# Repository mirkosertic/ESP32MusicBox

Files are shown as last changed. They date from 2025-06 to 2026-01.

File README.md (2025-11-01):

# ESP32 MusicBox



This project provides an ESP32 based music box with the following features:

* Simple 3-button control
* MP3 playback
* Integration with I2C RFID tag scanner
* Support for WiFi Grids with auto-reconnect to nearest access point
* MQTT status reporting / remote control
* Home Assistant integration with device autodiscovery
* Web-based user interface
* Integrated into your local network with SSDP / mDNS protocol
* WebDAV support for file / content management
* Optional Bluetooth A2DP output / Bluetooth Headphone output
* Special mode to start in Bluetooth Speaker mode, so it works as a Boombox.
* 3-band equalizer

## Supported hardware

* ESP32 (tested with Lolin D32 Pro with a lot of PSRAM recommended (8 MB), 4MB flash RAM is required)
* PN532 RFID Reader (i2c-Mode)
* SDCard Reader (SPI-Mode), is already mounted on a Lolin D32 Pro board
* NeoPixel / WS2812 based LEDs for status visualization

## Final product

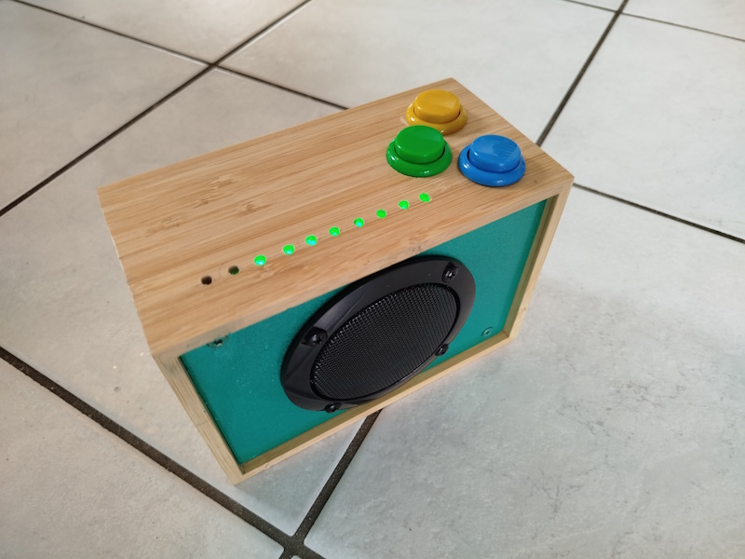
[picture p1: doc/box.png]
box


The KiCad 9.0 project is located in the kicad folder.

Here is the wiring schematic drawing:

schematics

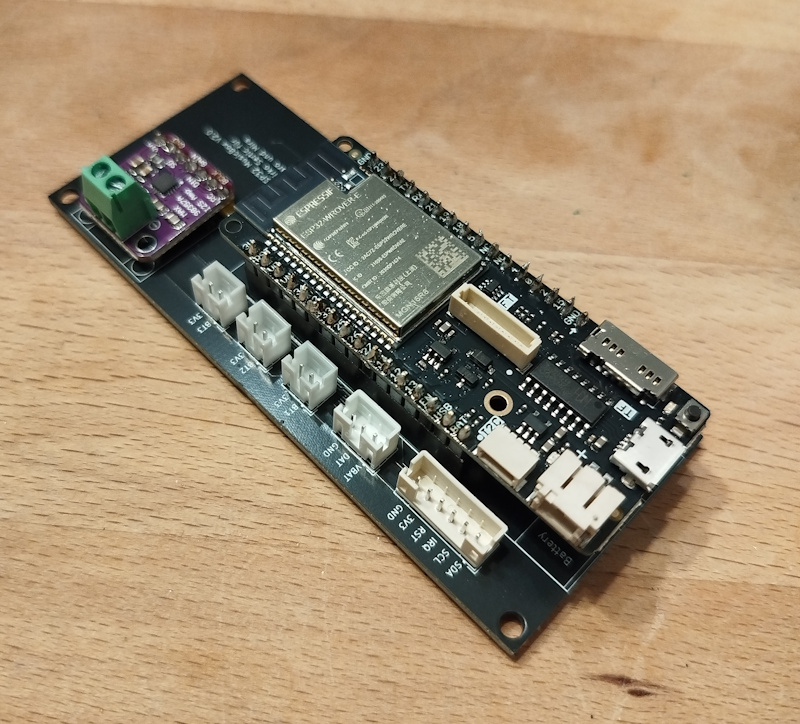
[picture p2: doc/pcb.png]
pcb


## Manual

Status visualization with LEDs:

- Boot-Sequence - LEDs enabled step by step to visualize boot progress
- Leds cycling in brightness - orange in case WiFi is not connected but enabled, green in case if playback paused or no playback yet
- Leds green from 0% to 100% filling the circle - Playback progress while playing something
- Leds blinking red - Unknown RFID card detected
- Leds blinking green - RFID card programmed / Known card detected
- Leds green to red - While changing volume
- Keep button 1 pressed during startup. Leds will turn blue to indicate Bluetooth Speaker mode.
- Yellow flashing LEDs indicate a Bluetooth pairing request while in Speaker mode. Press button 1 again to confirm the pairing. LEDs will flash in blue to confirm pairing
- Keep button 1 and button 2 pressed during playback to start from beginning

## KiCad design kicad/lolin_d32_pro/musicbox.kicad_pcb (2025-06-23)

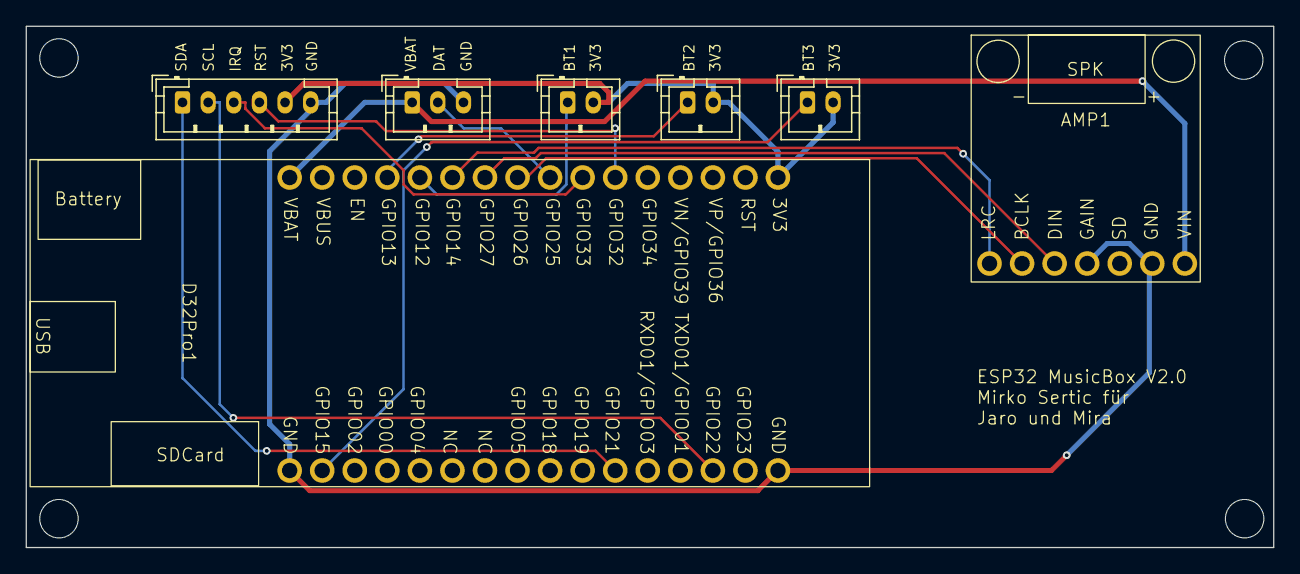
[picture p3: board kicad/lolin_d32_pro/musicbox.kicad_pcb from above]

Board: 2 copper layers, 97.3 x 40.7 mm, 7 parts (0 on the bottom side), 14 nets.

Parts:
AMP1: MAX98357A
BT1Con1, BT2Con1, BT3Con1: JST_PH_B2B-PH-K_1x02_P2.00mm_Vertical
D32Pro1: ESPD32Pro
NeoPixelCon1: JST_PH_B3B-PH-K_1x03_P2.00mm_Vertical
RFIDCon1: Conn_01x06_Socket; JST_PH_B6B-PH-K_1x06_P2.00mm_Vertical

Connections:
3V3: BT1Con1.2, BT2Con1.2, BT3Con1.2, D32Pro1.1 (3V3), RFIDCon1.5
/ADR_LED: D32Pro1.8 (GPIO25), NeoPixelCon1.2
/BT1: BT1Con1.1, D32Pro1.12 (GPIO12)
/BT2: BT2Con1.1, D32Pro1.13 (GPIO13)
/BT3: BT3Con1.1, D32Pro1.31 (GPIO15)
/I2C_SCL: D32Pro1.19 (GPIO22), RFIDCon1.2
/I2C_SDA: D32Pro1.22 (GPIO21), RFIDCon1.1
/I2S_BCK: AMP1.2 (BCLK), D32Pro1.9 (GPIO26)
/I2S_DIN: AMP1.3 (DIN), D32Pro1.10 (GPIO27)
/I2S_WS: AMP1.1 (LRC), D32Pro1.11 (GPIO14)
/RFID_IRQ: D32Pro1.7 (GPIO33), RFIDCon1.3
/RFID_RST: D32Pro1.6 (GPIO32), RFIDCon1.4
GND: AMP1.4 (GAIN), AMP1.6 (GND), D32Pro1.17 (GND), D32Pro1.32 (GND), NeoPixelCon1.3, RFIDCon1.6
VBAT: AMP1.7 (VIN), D32Pro1.16 (VBAT), NeoPixelCon1.1

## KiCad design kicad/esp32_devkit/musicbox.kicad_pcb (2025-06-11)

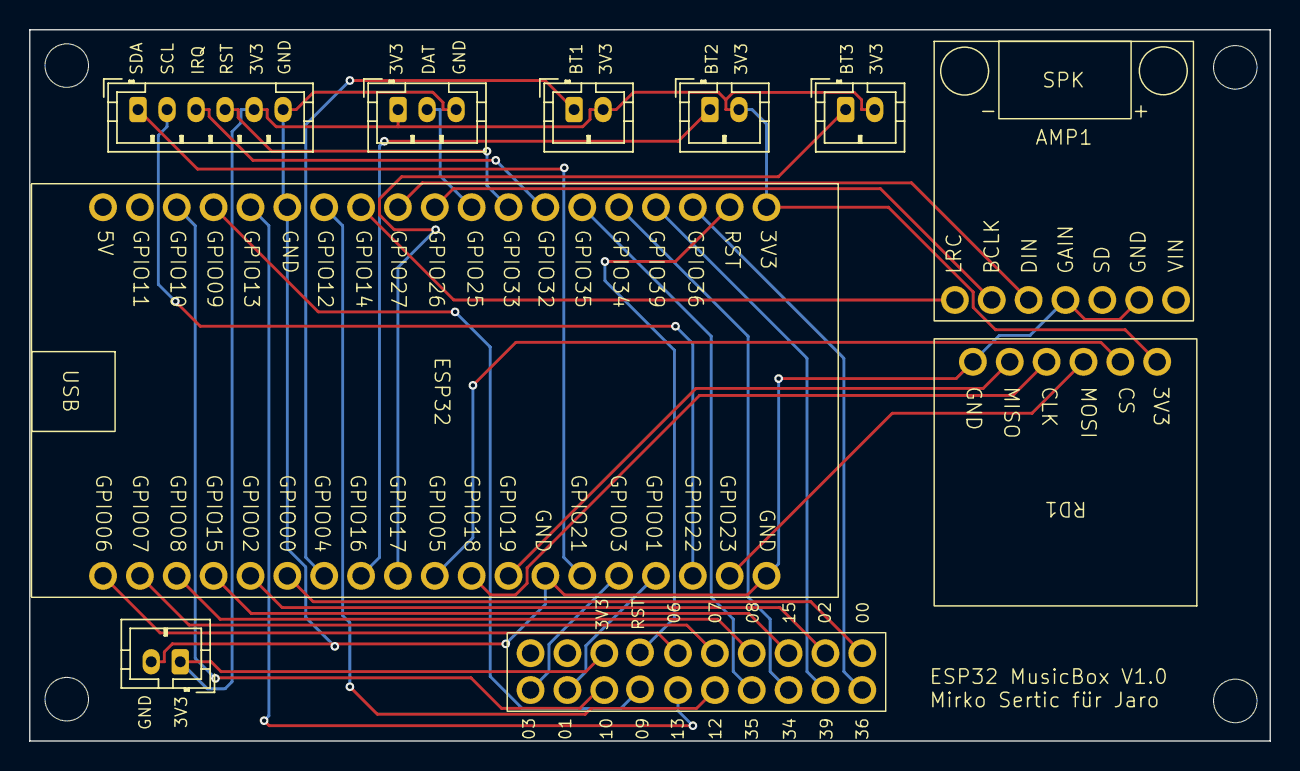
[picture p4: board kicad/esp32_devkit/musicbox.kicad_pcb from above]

Board: 2 copper layers, 85.5 x 49.0 mm, 10 parts (0 on the bottom side), 34 nets.

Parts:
AMP1: MAX98357A
BT1Con1, BT2Con1, BT3Con1: JST_PH_B2B-PH-K_1x02_P2.00mm_Vertical
ESP32: ESP32DevKit
IO1: IO; Pads_2x10
NeoPixelCon1: JST_PH_B3B-PH-K_1x03_P2.00mm_Vertical
PWRCon1: JST_PH_B2B-PH-K_1x02_P2.00mm_Vertical
RD1: SDCardReader
RFIDCon1: Conn_01x06_Socket; JST_PH_B6B-PH-K_1x06_P2.00mm_Vertical

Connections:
3V3: BT1Con1.2, BT2Con1.2, BT3Con1.2, ESP32.1 (3V3), IO1.18, NeoPixelCon1.1, PWRCon1.1, RD1.1 (VCC), RFIDCon1.5
/ADR_LED: ESP32.9 (GPIO25), NeoPixelCon1.2
/BT1: BT1Con1.1, ESP32.32 (GPIO04)
/BT2: BT2Con1.1, ESP32.31 (GPIO16)
/BT3: BT3Con1.1, ESP32.30 (GPIO17)
/GPIO00: ESP32.33 (GPIO00), IO1.11
/GPIO01: ESP32.23 (GPIO01), IO1.9
/GPIO02: ESP32.34 (GPIO02), IO1.12
/GPIO03: ESP32.24 (GPIO03), IO1.10
/GPIO06: ESP32.38 (GPIO06), IO1.16
/GPIO07: ESP32.37 (GPIO07), IO1.15
/GPIO08: ESP32.36 (GPIO08), IO1.14
/GPIO09: ESP32.16 (GPIO09), IO1.7
/GPIO10: ESP32.17 (GPIO10), IO1.8
/GPIO12: ESP32.13 (GPIO12), IO1.5
/GPIO13: ESP32.15 (GPIO13), IO1.6
/GPIO15: ESP32.35 (GPIO15), IO1.13
/GPIO34: ESP32.5 (GPIO34), IO1.3
/GPIO35: ESP32.6 (GPIO35), IO1.4
/GPIO36: ESP32.3 (GPIO36), IO1.1
/GPIO39: ESP32.4 (GPIO39), IO1.2
/I2C_SCL: ESP32.22 (GPIO22), RFIDCon1.2
/I2C_SDA: ESP32.25 (GPIO21), RFIDCon1.1
/I2S_BCK: AMP1.2 (BCLK), ESP32.10 (GPIO26)
/I2S_DIN: AMP1.3 (DIN), ESP32.11 (GPIO27)
/I2S_WS: AMP1.1 (LRC), ESP32.12 (GPIO14)
/RFID_IRQ: ESP32.7 (GPIO32), RFIDCon1.3
/RFID_RST: ESP32.8 (GPIO33), RFIDCon1.4
/RST: ESP32.2 (RESET), IO1.17
/SPI_MISO: ESP32.27 (GPIO19), RD1.5 (MISO)
/SPI_MOSI: ESP32.21 (GPIO23), RD1.3 (MOSI)
/SPI_SCK: ESP32.28 (GPIO18), RD1.4 (SCK)
/SPI_SS: ESP32.29 (GPIO05), RD1.2 (CS)
GND: AMP1.4 (GAIN), AMP1.6 (GND), ESP32.14 (GND), ESP32.20 (GND), ESP32.26 (GND), NeoPixelCon1.3, PWRCon1.2, RD1.6 (GND), RFIDCon1.6

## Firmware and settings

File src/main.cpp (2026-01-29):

#include "boomboxmode.h"
#include "leds.h"
#include "logging.h"
#include "pins.h"
#include "rfidplayermode.h"
#include "sensors.h"

#include <driver/rtc_io.h>
#include <esp_arduino_version.h>
#include <esp_idf_version.h>
#include <esp_sleep.h>
#include <esp_task_wdt.h>

Leds *leds = NULL;
Sensors *sensors = NULL;
Mode *mode = NULL;

void setup() {
	Serial.begin(115200);

	INFO("Setup started");
	INFO("Running on Arduino : %d.%d.%d", ESP_ARDUINO_VERSION_MAJOR, ESP_ARDUINO_VERSION_MINOR, ESP_ARDUINO_VERSION_PATCH);
	INFO("Running on ESP IDF : %s", esp_get_idf_version());
	INFO("Max  HEAP  is %d", ESP.getHeapSize());
	INFO("Free HEAP  is %d", ESP.getFreeHeap());
	INFO("Max  PSRAM is %d", ESP.getPsramSize());
	INFO("Free PSRAM is %d", ESP.getFreePsram());

	esp_sleep_wakeup_cause_t wakeupreason = esp_sleep_get_wakeup_cause();
	switch (wakeupreason) {
		case ESP_SLEEP_WAKEUP_EXT0: {
			INFO("Deepsleep Wakeup EXT0");
			break;
		}
		case ESP_SLEEP_WAKEUP_EXT1: {
			INFO("Deepsleep Wakeup EXT1");
			break;
		}
		case ESP_SLEEP_WAKEUP_TIMER: {
			INFO("Deepsleep Wakeup Timer");
			break;
		}
		case ESP_SLEEP_WAKEUP_TOUCHPAD: {
			INFO("Deepsleep Wakeup Touchpad");
			break;
		}
		default: {
			INFO("Wakeup not caused by known Deepsleep reason : %d", wakeupreason);
			break;
		}
	}

	INFO("Starting boot sequence");
	leds = new Leds();
	leds->begin();
	leds->setBootProgress(0);
	leds->setState(BOOT);

	sensors = new Sensors();
	if (sensors->isNextPressed()) {
		INFO("Booting into Bluetooth Boombox mode");
		mode = new BoomboxMode(leds, sensors);
	} else {
		INFO("Booting into RFID player mode");
		mode = new RfidPlayerMode(leds, sensors);
	}

	mode->setup();

	// TODO: Wakeup on RFID IRQ??? Will only work after RFIDReaderMode is active...
	INFO("Configuring Deepsleep wakeup");
	if (esp_sleep_enable_ext0_wakeup(GPIO_STARTSTOP, 1)) {
		// if (esp_sleep_enable_ext0_wakeup(GPIO_PN532_IRQ, 0)) {
		WARN("Failed to configure deepsleep!")
		while (true)
			;
	}
	rtc_gpio_pulldown_en(GPIO_STARTSTOP);
	rtc_gpio_pullup_dis(GPIO_STARTSTOP);

	INFO("Setup finished.");
	INFO("Max  HEAP  is %d", ESP.getHeapSize());
	INFO("Free HEAP  is %d", ESP.getFreeHeap());
	INFO("Max  PSRAM is %d", ESP.getPsramSize());
	INFO("Free PSRAM is %d", ESP.getFreePsram());
}

long lastIdleTime = -1;

void loop() {

	ModeStatus status = mode->loop();
	if (status == MODE_IDLE) {
		long now = millis();
		if (lastIdleTime == -1) {
			lastIdleTime = now;
		} else if (now - lastIdleTime > (AUTO_SHUTDOWN_IN_MINUTES * 60 * 1000)) {
			//} else if (now - lastIdleTime > 5000) {
			// Deep sleep
			INFO("Beeing idle for too long, going to deepsleep");
			mode->shutdown();
			INFO("This will not be logged...");
		}
	} else {
		lastIdleTime = -1;
	}

	esp_task_wdt_reset();
}

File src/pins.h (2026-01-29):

#ifndef PINS_H
#define PINS_H

// Make sure the the buttons are assigned to IO pins with pullup/puppdown resistors configurable by software!
// RTC GPIO for Deepsleep Wakeup
#define GPIO_STARTSTOP GPIO_NUM_12
#define GPIO_PREVIOUS  GPIO_NUM_13
#define GPIO_NEXT	   GPIO_NUM_15

#define GPIO_WIRE_SDA GPIO_NUM_21
#define GPIO_WIRE_SCL GPIO_NUM_22

// RTC GPIO for Deepsleep Wakeup
#define GPIO_PN532_IRQ GPIO_NUM_33
#define GPIO_PN532_RST GPIO_NUM_32

#define GPIO_NEOPIXEL_DATA GPIO_NUM_25

#define GPIO_I2S_BCK  GPIO_NUM_26
#define GPIO_I2S_WS	  GPIO_NUM_14
#define GPIO_I2S_DATA GPIO_NUM_27

#define GPIO_SPI_SS	  GPIO_NUM_4
#define GPIO_SPI_SCK  GPIO_NUM_18
#define GPIO_SPI_MOSI GPIO_NUM_23
#define GPIO_SPI_MISO GPIO_NUM_19

// analogRead(GPIO_VOLTAGE_MEASURE) / 4096.0 * 7.445
#define GPIO_VOLTAGE_MEASURE GPIO_NUM_35

#endif

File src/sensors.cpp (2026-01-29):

#include "sensors.h"

#include "logging.h"
#include "pins.h"

Sensors::Sensors() {
	pinMode(GPIO_VOLTAGE_MEASURE, INPUT);

	this->resetCommandSent = false;

	this->startstop = new Button(GPIO_STARTSTOP, 300, [this](ButtonAction action) {
        if (action == PRESSED)
        {
            INFO("Start / Stop button pressed");
            this->handler->toggleActiveState();
        } });

	this->prev = new Button(GPIO_PREVIOUS, 300, [this](ButtonAction action) {
        if (action == RELEASED) 
        {
            INFO("Prev button released");            
            this->handler->previous();
        }
        if (action == PRESSED_FOR_LONG_TIME && !this->next->isPressesForALongTime())
        {   
            if (this->handler->volumeDown())
            {
                INFO("Decrementing volume");
            }
        } });

	this->next = new Button(GPIO_NEXT, 300, [this](ButtonAction action) {
        if (action == RELEASED)
        {
            INFO("Next button released");                        
            this->handler->next();
        }
        if (action == PRESSED_FOR_LONG_TIME && !this->prev->isPressesForALongTime())
        {
            if (this->handler->volumeUp())
            {
                INFO("Incrementing volume");
            }
        } });
}

void Sensors::begin(UserfeedbackHandler *handler) {
	this->handler = handler;
}

Sensors::~Sensors() {
	delete this->prev;
	delete this->next;
	delete this->startstop;
}

void Sensors::loop() {
	static long lastcheck = millis();

	// We check the buttons not in every main loop iteration, we check them timed...
	long now = millis();
	if (now - lastcheck > 30) {
		lastcheck = now;
		this->prev->loop();
		this->next->loop();
		this->startstop->loop();

		if (this->prev->isPressesForALongTime() && this->next->isPressesForALongTime()) {
			if (!this->resetCommandSent) {
				INFO("Resetting playback to start");
				this->resetCommandSent = true;
				this->handler->resetPlaybackToStart();
			} else {
				DEBUG("Reset command already sent.");
			}
		} else {
			this->resetCommandSent = false;
		}
	}
}

bool Sensors::isStartStopPressed() {
	return this->startstop->isPressed();
}

bool Sensors::isPreviousPressed() {
	return this->prev->isPressed();
}

bool Sensors::isNextPressed() {
	return this->next->isPressed();
}

int Sensors::getBatteryVoltage() {
	int value = analogRead(GPIO_VOLTAGE_MEASURE);
	INFO("Battery voltage ADC is %d", value);
	return (int) (value / 4096.0 * 7.445 * 1000.0);
}

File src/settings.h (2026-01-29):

#ifndef SETTINGS_H
#define SETTINGS_H

#include <Arduino.h>

#include <FS.h>
#include <vector>

class Settings {
private:
	FS *fs;
	String configurationfilename;
	bool wlan_enabled = WLAN_ENABLED;
	String wlan_sid = WLAN_SID;
	String wlan_pwd = WLAN_PASSWORD;

	bool mqtt_enabled = MQTT_ENABLED;
	String mqtt_server = MQTT_SERVER;
	int mqtt_port = MQTT_PORT;
	String mqtt_username = MQTT_USERNAME;
	String mqtt_password = MQTT_PASSWORD;

	bool voice_enabled = VOICE_ENABLED;
	String voice_server = VOICE_SERVER;
	int voice_port = VOICE_PORT;
	String voice_token = VOICE_TOKEN;

	String deviceName = DEVICENAME;
	std::vector<String> blueoothdeviceprefixes = {BLUETOOTH_DEVICEPREFIX};

	float volumeIncrement = 0.015;

	float equalizerLow = 1.0;
	float equalizerMiddle = 1.0;
	float equalizerHigh = 1.0;

public:
	Settings(FS *fs, String configurationfilename);

	bool readFromConfig();
	bool writeToConfig();

	String getDeviceName();

	bool isWiFiEnabled();

	bool isMQTTEnabled();
	String getMQTTServer();
	int getMQTTPort();
	String getMQTTUsername();
	String getMQTTPassword();

	bool isVoiceAssistantEnabled();
	String getVoiceAssistantServer();
	int getVoiceAssistantPort();
	String getVoiceAssistantAccessToken();
	float getVoiceAssistantVolumeMultiplier();
	int getVoiceAssistantWakeWordTimeout();
	int getVoiceAssistantAutomaticGain();
	int getVoiceAssistantNoiseSuppressionLevel();

	void initializeWifiFromSettings();

	void rescanForBetterNetworksAndReconfigure();

	String getSettingsAsJson();
	void setSettingsFromJson(String json);

	bool isValidDeviceToPairForBluetooth(String ssid);

	String computeTechnicalName();

	float getVolumeIncrement();

	float getEqualizerLow();
	float getEqualizerMiddle();
	float getEqualizerHigh();

	float getBootVolume();
};

#endif

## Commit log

2024-09-19 VoiceAssistant integration prototype
2024-09-20 Working on threading issues...
    [main.cpp]
2024-09-20 Threading fix
2024-09-20 Working on threading issues
    [main.cpp]
2024-09-21 Working von Voice Assistant threading
2024-09-25 Bug fixing voice assistant integration
    [main.cpp]
2024-09-28 Refactored button control logic into separate class
2024-09-30 Debugging and bug fixing
    [main.cpp]
2024-10-27 Bug fixing / added KiCad project
    [musicbox.kicad_pcb, musicbox.kicad_sch]
2024-10-27 Updated the documentation
    [musicbox.kicad_sch]
2024-10-31 Working on visual feedback using NeoPixels
    [AudioKitPINMapping.xlsx]
2025-05-26 Working on newer prototype
    [musicbox.kicad_sch]
2025-05-28 Working on ewer version
    [musicbox.kicad_sch]
2025-06-05 Bug fixing / WebDAV
    [main.cpp]
2025-06-06 Bug fixing
    [musicbox.kicad_sch]
2025-06-18 BUg fixing / BT speaker mode support
    [custom_4mb_noota.csv, custom_8mb_ota.csv]
2025-06-19 Fixed speaker volume level
    [main.cpp]
2025-06-23 Working on Bluetooth Speaker mode
    [musicbox-B_Cu.gbl, musicbox-B_Mask.gbs, musicbox-B_Paste.gbp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]
2025-06-23 Updated Gerbers for Lolin D32 Pro
    [musicbox-B_Cu.gbl, musicbox-B_Mask.gbs, musicbox-B_Paste.gbp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]
2025-07-06 Bug fixed deepsleep implementation
    [main.cpp, mode.cpp, pins.h]
2025-07-08 Bug fixing deepsleep implementation
    [main.cpp, rfidplayermode.cpp]
2025-07-09 Bug fixing automatic network disconnect
    [main.cpp, rfidplayermode.cpp, settings.h]
2025-07-13 Bug fixing volume control
    [sensors.cpp]
2025-07-22 Testing LED colors
2025-07-25 Using another button for bluetooth functionalities
2025-07-25 Bug fix : wrong playback direction after navigation
    [rfidplayermode.cpp]
2025-07-27 Use last playyback after reboot
    [rfidplayermode.cpp]
2025-07-28 Use last playback after reboot
    [rfidplayermode.cpp, settings.h]
2025-08-02 Bug fix in prev button navigation
    [rfidplayermode.cpp]
2025-11-01 Added playback reset functionality and reversed led order
2026-03-13 Bug fixing / library updates
    [rfidplayermode.cpp]
